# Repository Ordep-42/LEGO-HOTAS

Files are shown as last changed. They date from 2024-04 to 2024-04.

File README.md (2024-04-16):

# LEGO Hands On Throttle And Stick (Stick WIP)

#### An Arduino Pro Micro based HOTAS setup built entirely with LEGO pieces

## Project Overview

The goal of this project is to create a fully functional HOTAS system using LEGO as the main building material. The Arduino Pro Micro is used to interface with the computer and translate the inputs from the controls into commands that can be recognized by games.

Keep in mind that I made this HOTAS as a personal project and this github repository is merely a way to share my design. The STUDio MOC i made is inside the assets/LEGO-Model folder.

MOC Render

## Micro-controller used

After hours of countless research I've decided to use the Arduino Pro Micro. The main reasons being cost and ease of programming. It has the Atmega32U4 as the main controller, which is one of the cheapest MCUs with native HID support. Therefore the computer can see it as a mouse, keyboard or joystick without needing extra hardware or complex programming. 

Since It's a kind of official Arduino model, it has all the benefits of the Arduino eco-system. Which means there are thousands of projects and documentation on the internet around DIY gamepads and similar setups. In this project I use two libraries from the Arduino eco-system, the [Joystick](https://github.com/MHeironimus/ArduinoJoystickLibrary) library and the [Keypad](https://github.com/Chris--A/Keypad) library.
 
## Features

- 11 Buttons (9 on the base and 2 on the handle);
- Dual axis thumbstick;
- The throttle itself;

I tried my best to emulate the shape and size of the F-18 and F-14 throttle handles. I also added a feature so that it hinges on the shaft so that I dont get my hand in a weird position when at full throttle.

Full throttle with tilt

## Fitting everything together

I used a combination of 22AWG wire (from old computer PSUs), some perfboard and Dupoint (Arduino-y type) connectors to connect all the electronics in the base, and some 9 conductor wire from an old computer case (specifically the audio cable from the front panel connectors).

I placed the throttle potentiometer right here with the pins pointing outwards, I passed the cable through the 2 x 1 brick with holes on the left side of the picture.

Pot location

The thumbstick is double-sided taped to this plate on the right-hand side of the handle, roughly where my thumb sits.

Thumbstick location

Finding a place for the Arduino to sit was kinda difficult considering the amount of supports and internal pillars this thing has to make it durable. I endend up placing it here right above the main button matrix on the base.

I used 9 15mm normally open pushbuttons for the keypad on the base. They just sit on top of the base top cover and soldered them together from underneath. 

MCU location

## Circuit Schematic

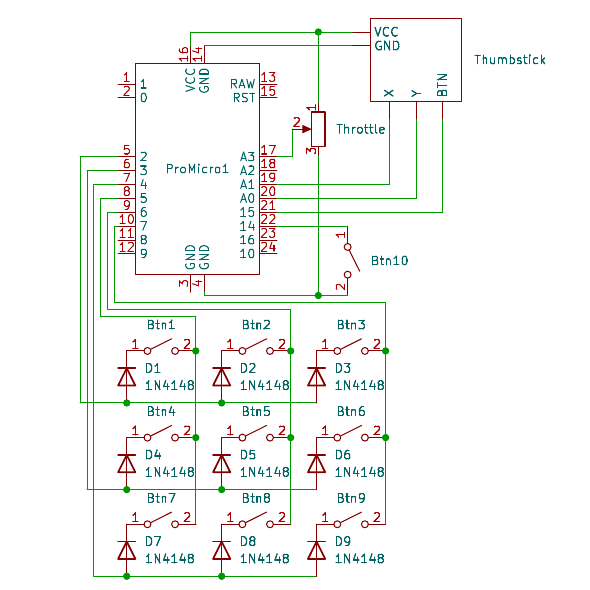
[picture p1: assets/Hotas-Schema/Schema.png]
Electric Schematic


The schematic is fairly simple, I used common 1N4148 diodes to prevent ghosting and masking on the base buttons and have them connected like the schematic so that the "Conventional" button no.1 on a keypad is actually the first button on the gamepad configuration wizard on Windows.

## Also check:

* [r/HotasDIY](https://www.reddit.com/r/HotasDIY/) for the wonderful community and ideas.
* [u/the_arrgyle](https://www.reddit.com/user/the_arrgyle/) for the original inspiration for this project.

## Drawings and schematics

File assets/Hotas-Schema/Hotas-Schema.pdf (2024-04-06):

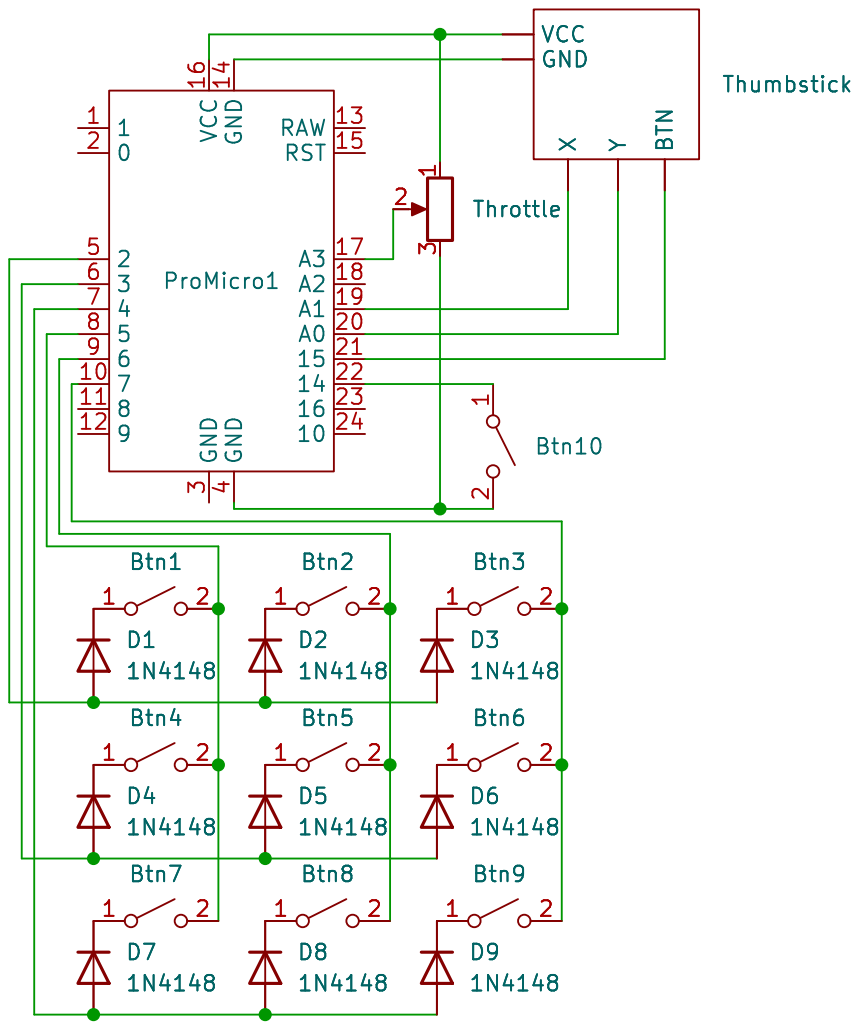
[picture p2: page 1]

1 2 Btn2 D2

1 2 Btn4 D4 | 1 2 Btn5

Id: 1/1 Title: File: Hotas-Schema.kicad_sch Sheet: /
1.0 Lego Throttle joystick schematic

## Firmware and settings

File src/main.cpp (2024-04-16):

#include "config.h"

Keypad throttleBase = Keypad(makeKeymap(baseButtonMap), rowPins, colPins, ROWS, COLS);

Joystick_ Joystick(0x03, 0x04,
                  handleButtonCount + baseButtonCount, 0,
                  false, false, false,
                  true, true, false,
                  false, true,
                  false, false, false);

void setup() {
  initJoystick();
}

void loop() {
  updateJoystick();
  delay(10);
}

void initJoystick() {
  Joystick.begin();
  for (int button = 0; button < handleButtonCount; button++) {
    pinMode(handleButtonMap[button], INPUT_PULLUP);
    lastButtonState[button] = 0;
  }
  Joystick.setThrottleRange(0, 930);
}

void updateJoystick() {
  checkHandleButtons();
  checkThrottleBase();

  throttleState = analogRead(throttlePin);
  Joystick.setThrottle(throttleState);

  thumbXAxis = analogRead(thumbXPin);
  Joystick.setXAxis(thumbXAxis);

  thumbYAxis = analogRead(thumbYPin);
  Joystick.setYAxis(thumbYAxis);
}

void checkHandleButtons() {
  for (int button = 0; button < handleButtonCount; button++) {
    int buttonState = digitalRead(handleButtonMap[button]);
    if (buttonState != lastButtonState[button]) {
      Joystick.setButton(handleButtonMap[button], buttonState);
      lastButtonState[button] = buttonState;
    }
  }
}

void checkThrottleBase() {
  if (throttleBase.getKeys()) {
    for (int button = 0; button < baseButtonCount; button++) {
      if (throttleBase.key[button].stateChanged) {
        switch (throttleBase.key[button].kstate) {
          case PRESSED:
            Joystick.setButton(throttleBase.key[button].kchar, 1);
            break;
          case IDLE:
            Joystick.setButton(throttleBase.key[button].kchar, 0);
            break;
        }
      }
    }
  }
}

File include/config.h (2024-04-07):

#ifndef CONFIG_H
#define CONFIG_H

#include <Arduino.h>
#include <Joystick.h>
#include <Keypad.h>

#define baseButtonCount 9
#define ROWS 3
#define COLS 3
#define handleButtonCount 2

/*                 +-----+
        +----------| USB |----------+
        |          +-----+          |
    D1  | [ ]1/TX            RAW[ ] |
    D0  | [ ]0/RX            GND[ ] |
        | [ ]GND             RST[ ] |
        | [ ]GND             VCC[ ] |
    D2  | [M]2/SDA   ___      A3[P] |   D21
    D3  |~[M]3/SCL  /   \     A2[ ] |   D20
    D4  | [M]4/A6  / PRO \    A1[J] |   D19
    D5  |~[M]5     \  µ  /    A0[J] |   D18
    D6  |~[M]6/A    \___/ SCK/15[B] |   D15
    D7  | [M]7           MISO/14[B] |   D14
    D8  | [ ]8/A8        MOSI/16[ ] |   D16
    D9  |~[ ]9/A9         A10/10[ ]~|   D10
        |                           |
        +---------------------------+
*/

//------------------------------------------
// [T] Throttle potentiometer
//------------------------------------------
#define throttlePin A3

unsigned int throttleState;

//------------------------------------------
// [J] Thumbstick axis
//------------------------------------------
#define thumbXPin A1
#define thumbYPin A0

unsigned int thumbXAxis, thumbYAxis;

//------------------------------------------
// [B] Handle Buttons
//------------------------------------------
const int handleButtonPins[handleButtonCount] = {14, 15};
const int handleButtonMap[handleButtonCount] = {9, 10};
int lastButtonState[handleButtonCount];

//------------------------------------------
// [M] Base button matrix
//------------------------------------------
byte rowPins[ROWS] = {2, 3, 4};
byte colPins[COLS] = {5, 6, 7};

char baseButtonMap[ROWS][COLS] = {
    {0, 1, 2},
    {3, 4, 5},
    {6, 7, 8}
};

void initJoystick();
void updateJoystick();
void checkHandleButtons();
void checkThrottleBase();

#endif

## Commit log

2024-01-18 Add board configuration and pin maps
2024-01-18 Throttle handle and base update functions
2024-03-03 Add and track gitignore
2024-03-04 Create KiCad project and start schematic drawing
    [Hotas-Schema.kicad_pcb, Hotas-Schema.kicad_sch]
2024-03-04 Finish the circuit schematic
    [Hotas-Schema.kicad_sch]
2024-03-04 Modify throttlePin in header file to use a single connector for potentiometer
2024-03-05 Change labels in schematic
    [Hotas-Schema.kicad_sch]
2024-04-06 Create schema image and fix readme
    [Hotas-Schema.kicad_sch]
2024-04-07 Add Arduino ASCII art to config_h to pin definitions
2024-04-16 Change from HOLD to PRESSED in the checkThrottleBase() switch case
